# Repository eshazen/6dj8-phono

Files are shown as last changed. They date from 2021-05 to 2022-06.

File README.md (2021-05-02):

# 6dj8 phono preamp

This is a project to build a 6DJ8 (ECC88) tube phono stage as inspired by RJM audio (phonoclone.com).  The 6DJ8 seems to be out of production, but still readily available.

## Power board:

IEC power input, fuse, switch, neon as in https://github.com/eshazen/6cy7-amp.  PT, chokes mounted on PCB also.  Single noval socket for 6CA4 (ceramic).  Two B+ outputs for two channels.

## Channel board (2):

Single tube (6DJ8/ECC88) per channel.  RCA inputs and outputs, plus GND.  Power connector.

## Progress

*2021-05-01* - Schematics done for PS and amp.  Footprints done and DigiKey numbers on amp schematic, starting placement

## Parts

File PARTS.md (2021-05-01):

Notes on parts

# Power Supply

Planning to use the tube-rectified, inductor output power supply.

PT:  nom. 625VCT @ 50mA.  

Looking at Hammond 272X:  620VCT @ 80mA, 5VCT @ 2A, 6.3VCT @ 2.4A

For the chokes.  20H 30mA is not readily available, but
the Hammond 155J is 15H @ 30mA.  5H @ 30mA is a Hammond 155H

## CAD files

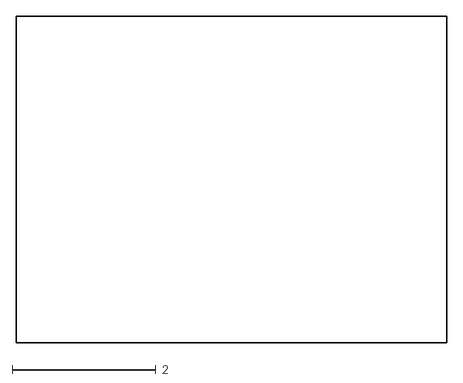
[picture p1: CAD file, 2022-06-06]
boards/phono-amp/DXF/phono-amp-Edge_Cuts.dxf
6.00 x 4.55

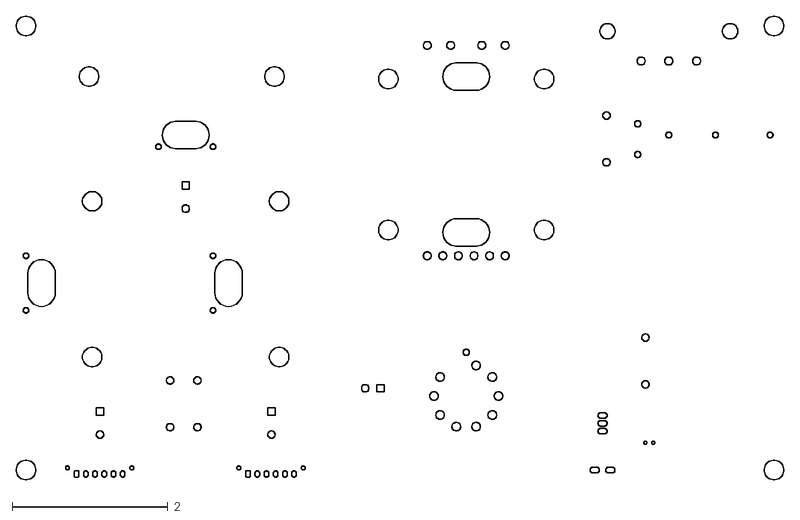
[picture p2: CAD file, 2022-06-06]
boards/phono-power/DXF/phono-power-F_Cu.dxf
9.85 x 5.95

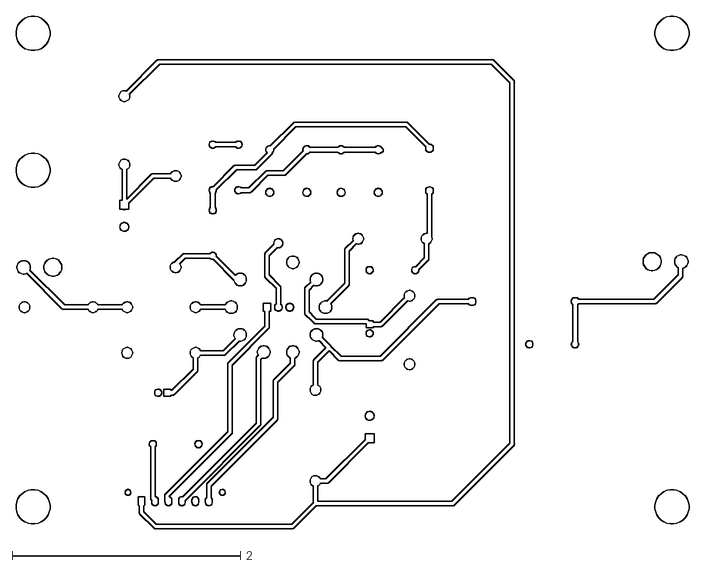
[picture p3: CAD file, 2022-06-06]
boards/phono-amp/DXF/phono-amp-F_Cu.dxf
5.90 x 4.49

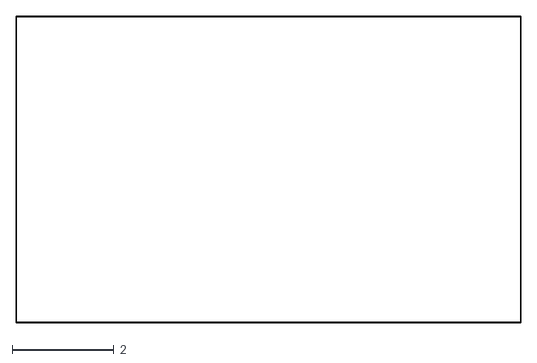
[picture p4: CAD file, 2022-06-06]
boards/phono-power/DXF/phono-power-Edge_Cuts.dxf
9.90 x 6.00

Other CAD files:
boards/phono-power/DXF/phono-power-F_SilkS.dxf

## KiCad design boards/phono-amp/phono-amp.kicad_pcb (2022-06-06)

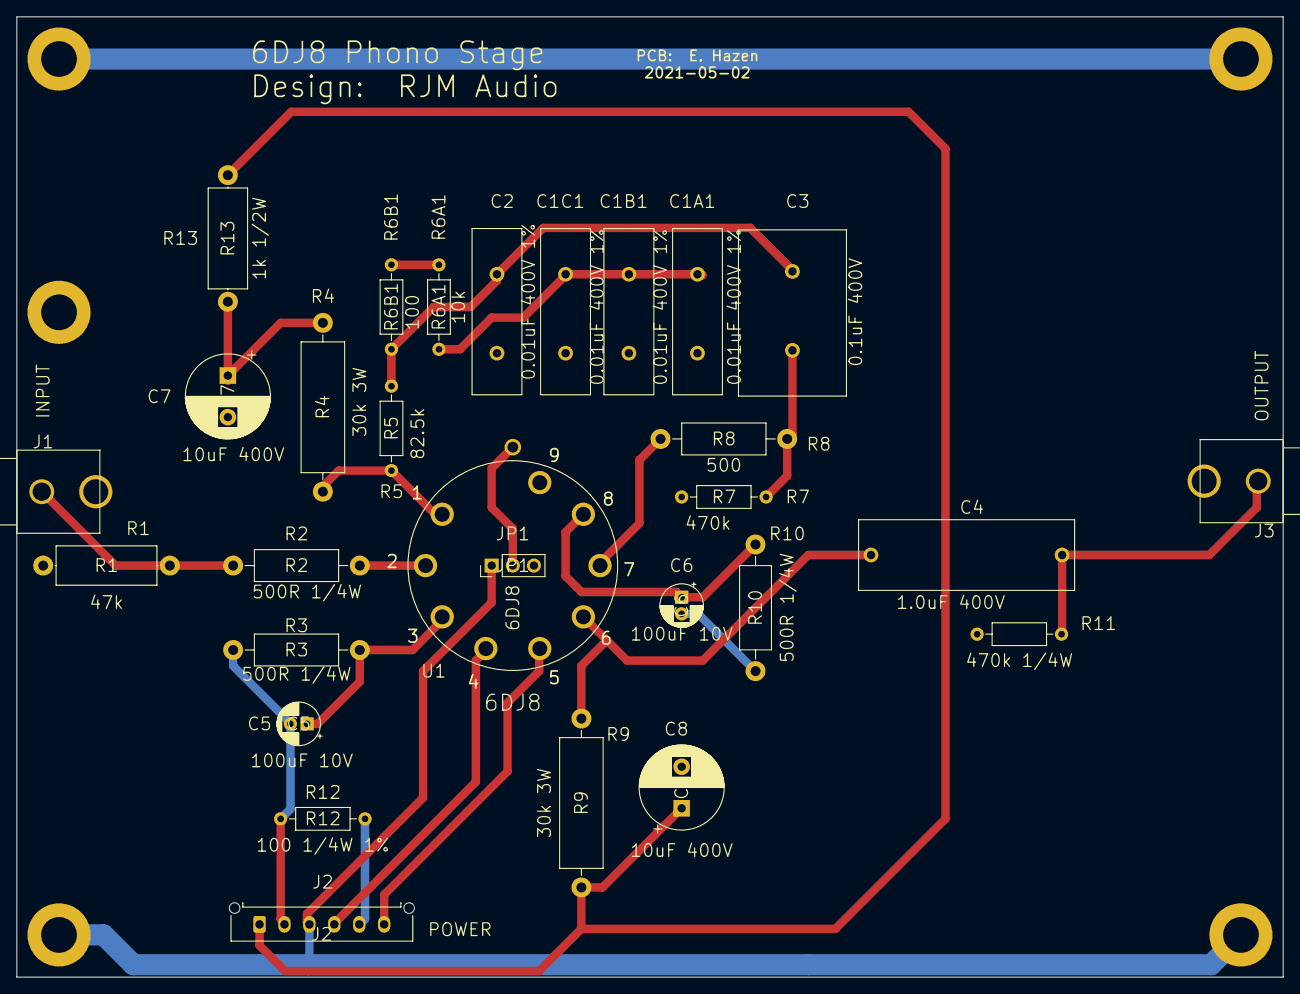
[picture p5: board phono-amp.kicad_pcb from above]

Board: 2 copper layers, 152.4 x 115.6 mm, 34 parts (0 on the bottom side), 20 nets.

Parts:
C1A1, C1B1, C1C1, C2: 0.01uF 400V 1%; CAP_L20_W6.4_P9.5
C3: 0.1uF 400V; CAP_L20_W13_P9.5
C4: 1.0uF 400V; CAP_L26_W8.5_P22.5
C5, C6: 100uF 10V; CP_Radial_D5.0mm_P2.00mm
C7, C8: 10uF 400V; CP_Radial_D10.0mm_P5.00mm
H1, H2, H3, H4, H5: MountingHole_Pad; MountingHole_4.3mm_M4_ISO7380_Pad
J1: INPUT; rca-single-klpx
J2: POWER; Molex_Micro-Fit_3.0_43650-0615_1x06_P3.00mm_Vertical
J3: OUTPUT; rca-single-klpx
JP1: 6DJ8; PinHeader_1x03_P2.54mm_Vertical
R1: 47k; R_Axial_DIN0414_L11.9mm_D4.5mm_P15.24mm_Horizontal
R2, R3, R10: 500R 1/4W; R_Axial_DIN0411_L9.9mm_D3.6mm_P15.24mm_Horizontal
R4, R9: 30k 3W; R_Axial_DIN0516_L15.5mm_D5.0mm_P20.32mm_Horizontal
R5: 82.5k; R_Axial_DIN0207_L6.3mm_D2.5mm_P10.16mm_Horizontal
R6A1: 10k; R_Axial_DIN0207_L6.3mm_D2.5mm_P10.16mm_Horizontal
R6B1: 100; R_Axial_DIN0207_L6.3mm_D2.5mm_P10.16mm_Horizontal
R7: 470k; R_Axial_DIN0207_L6.3mm_D2.5mm_P10.16mm_Horizontal
R8: 500; R_Axial_DIN0411_L9.9mm_D3.6mm_P15.24mm_Horizontal
R11: 470k 1/4W; R_Axial_DIN0207_L6.3mm_D2.5mm_P10.16mm_Horizontal
R12: 100 1/4W 1%; R_Axial_DIN0207_L6.3mm_D2.5mm_P10.16mm_Horizontal
R13: 1k 1/2W; R_Axial_DIN0414_L11.9mm_D4.5mm_P15.24mm_Horizontal
U1: 6DJ8; P-ST9-700-PC

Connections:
Earth_Protective: H1.1, H2.1, H3.1, H4.1, J2.3, JP1.1
GND: C1A1.2, C1B1.2, C1C1.2, C2.2, C5.2, C6.2, C7.2, C8.2, H5.1, J1.2, J2.2, J3.2, JP1.3, R1.1, R3.1, R7.1, R10.1, R11.1, R12.1, U1.9
unnamed: C1A1.1, C1B1.1, C1C1.1, R6A1.1
unnamed: C2.1, C3.2, R5.1, R6B1.2
unnamed: C3.1, R7.2, R8.2
unnamed: C4.1, J3.1, R11.2
unnamed: C4.2, R9.1, U1.6
unnamed: C5.1, R3.2, U1.3
unnamed: C6.1, R10.2, U1.8
unnamed: C7.1, R4.2, R13.2
unnamed: J1.1, R1.2, R2.2
unnamed: J2.4, U1.4
unnamed: J2.5, R12.2
unnamed: J2.6, U1.5
unnamed: JP1.2, U1.10
unnamed: R2.1, U1.2
unnamed: R4.1, R5.2, U1.1
unnamed: R6A1.2, R6B1.1
unnamed: R8.1, U1.7
VBUS: C8.1, J2.1, R9.2, R13.1

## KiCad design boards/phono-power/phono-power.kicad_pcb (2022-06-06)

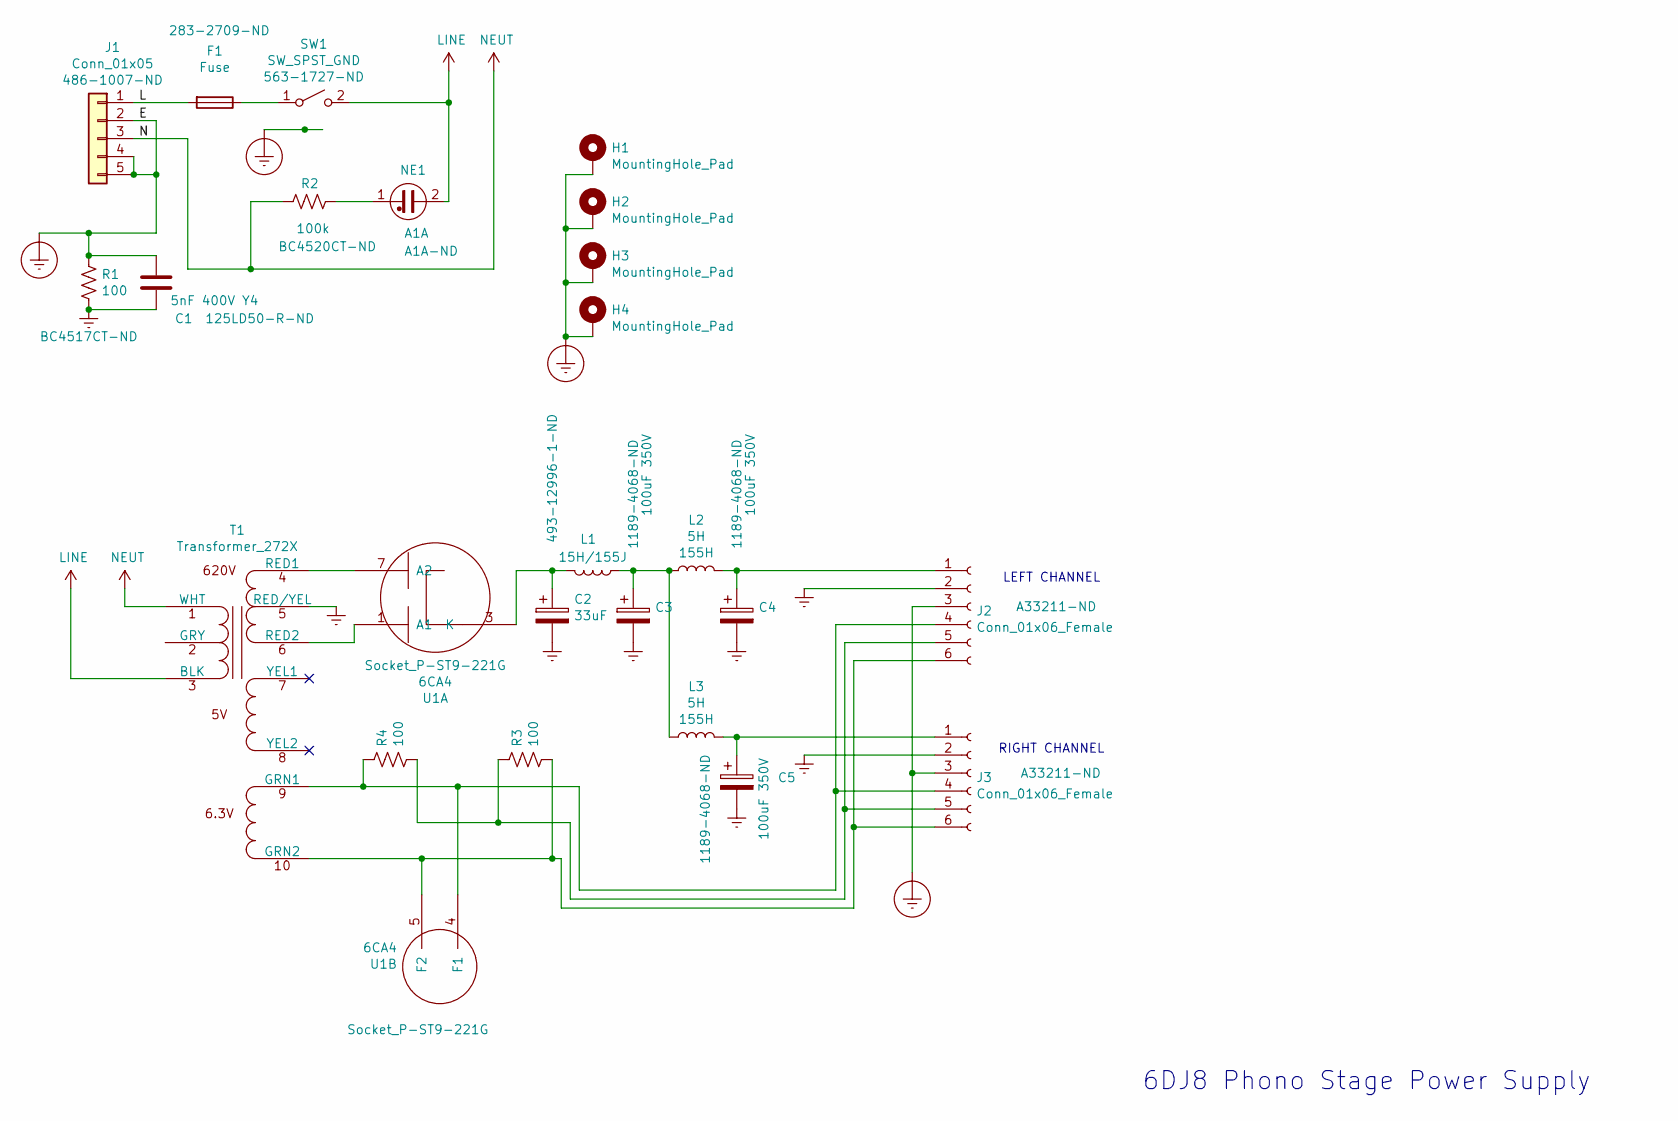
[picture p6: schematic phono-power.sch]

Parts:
C1: 5nF 400V Y4; C_Disc_D11.0mm_W5.0mm_P10.00mm
C2: 33uF; CP_Radial_D12.5mm_P5.00mm
C3, C4, C5: 100uF 350V; CP_Radial_D18.0mm_P7.50mm
F1: Fuse; HBH-I-R
H1, H2, H3, H4: MountingHole_Pad; Mtg6-32
J1: Conn_01x05; GSP1.8101.1
J2, J3: Conn_01x06_Female; Molex_Micro-Fit_3.0_43650-0615_1x06_P3.00mm_Vertical
L1: 15H/155J; 156L
L2, L3: 5H; 155H
NE1: A1A
R1, R3, R4: 100; R_Axial_DIN0414_L11.9mm_D4.5mm_P15.24mm_Horizontal
R2: 100k; R_Axial_DIN0414_L11.9mm_D4.5mm_P15.24mm_Horizontal
SW1: SW_SPST_GND; 8GA1016-Z
T1: Transformer_272X; Hammond-272X
U1: 6CA4; P-ST9-700-PC

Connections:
/L: F1.2, J1.1
Earth: C1.1, C2.2, C3.2, C4.2, C5.2, J2.2, J3.2, R1.2, T1.5 (RED/YEL)
Earth_Protective: C1.2, H1.1, H2.1, H3.1, H4.1, J1.2, J1.4, J1.5, J2.3, J3.3, R1.1, SW1.4 (G1), SW1.5 (G2)
LINE: NE1.2, SW1.2 (B), T1.3 (BLK)
NEUT: J1.3, R2.2, T1.1 (WHT)
unnamed: C2.1, L1.2, U1.3 (K)
unnamed: C3.1, L1.1, L2.1, L3.1
unnamed: C4.1, J2.1, L2.2
unnamed: C5.1, J3.1, L3.2
unnamed: F1.1, SW1.1 (A)
unnamed: J2.4, J3.4, R4.1, T1.9 (GRN1), U1.4 (F1)
unnamed: J2.5, J3.5, R3.1, R4.2
unnamed: J2.6, J3.6, R3.2, T1.10 (GRN2), U1.5 (F2)
unnamed: NE1.1, R2.1
unnamed: T1.4 (RED1), U1.7 (A2)
unnamed: T1.6 (RED2), U1.1 (A1)

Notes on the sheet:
6DJ8 Phono Stage Power Supply
LEFT CHANNEL
RIGHT CHANNEL

Board: 2 copper layers, 24 parts (0 on the bottom side), 16 nets, no tracks yet.

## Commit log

2021-05-01 First version power supply schematic
    [phono-power.kicad_pcb, phono-power.sch]
2021-05-01 amp schematic draft
    [phono-amp.kicad_pcb, phono-amp.sch]
2021-05-02 footprints done, starting placement
    [phono-amp.kicad_pcb, phono-amp.sch]
2021-05-02 layout underway
    [phono-amp.kicad_pcb]
2021-05-02 Amp PCB done?
    [phono-amp.kicad_pcb, phono-amp.sch]
2021-05-02 Pause to consider board sizes
    [phono-amp.kicad_pcb, phono-power.kicad_pcb, phono-power.sch]
2022-06-06 synching up
    [phono-amp-Edge_Cuts.dxf, phono-amp-F_Cu.dxf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]
